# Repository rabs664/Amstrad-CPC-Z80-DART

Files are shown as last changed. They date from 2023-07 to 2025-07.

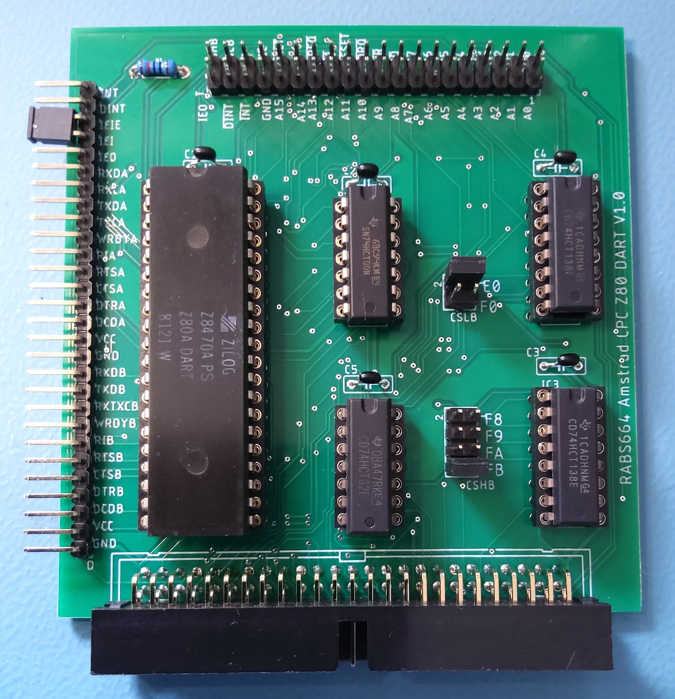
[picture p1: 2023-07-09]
Images/assembled-board.jpg

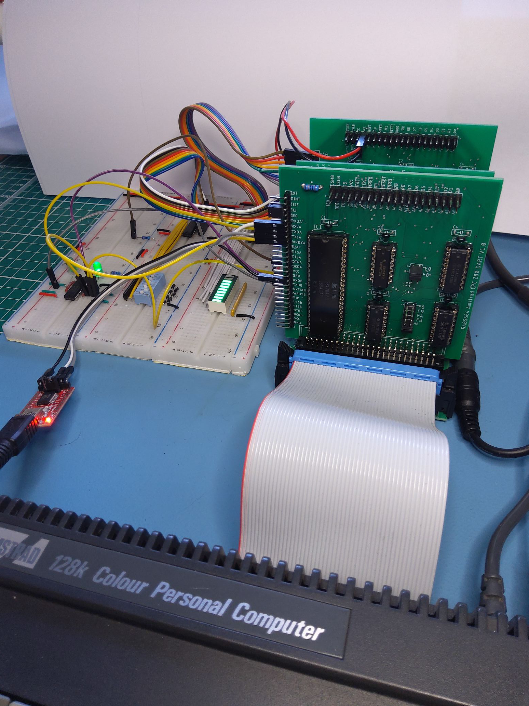
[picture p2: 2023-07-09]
Images/board-on-test.jpg

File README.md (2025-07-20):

# Amstrad CPC Z80 DART
Simple Z80 DART board compatible with the Amstrad CPC and MX4 connector.

assembled-board

## Objective
Prototyping board to learn about the Z80 DART, and how to write Z80 assembly using an Amstrad CPC.

## Background
Part of a number of modular cards using Z80 associated peripherals and the Amstrad CPC.

See also;
[Amstrad CPC 2855 PIO](https://github.com/rabs664/Amstrad-CPC-8255-PIO)

## Backplane
[CPC Amstrad Expansion Backplane by revaldinho](https://github.com/revaldinho/cpc_ram_expansion/wiki/CPC-Expansion-Backplane)

## IO Addressing
The IO Address can be selected using two sets of jumpers (CS_HB and CS_LB), supporting the following base address.

* F8E0 and F8F0
* F9E0 and F9F0
* FAE0 and FAF0
* FBE0 and FBF0

See [CPC Wiki IO Port Summary](https://www.cpcwiki.eu/index.php/I/O_Port_Summary) for a list of known IO ports used on the Amstrad CPC.

## Testing
The Z80 DART board has been built and simple testing has been completed on an Amstrad CPC 6128.

Note testing was completed with a Z80 CTC board for the baud clock generation. The Amstrad Clock can be used as a baud clock but this will result in a non standard baud rate.

Note also an FTDI Serial Adapter was used to connect to a putty session.

IEI was tied high (via a 10K resistor) using a jumper to IEIE. 

## PCBs
PCBs are available from [Seeed Studio](https://www.seeedstudio.com/Simple-Z80-DART-board-compatible-with-the-Amstrad-CPC-and-MX4-connecto-g-1395237).

## Components
This [Digi-Key List](https://www.digikey.co.uk/en/mylists/list/F0CQ96V54G) contains all components excluding the Z80 DART and FTDI Serial Adapter.

Note the right angled header for the port connections was not available at the time of producing this list but all other components were in stock for shipping immediately.

## Assembler
[RASM](https://github.com/EdouardBERGE/rasm)

## Resources
[CPCWiki](https://www.cpcwiki.eu/index.php/Main_Page)

Z80 Application by James W Coffron ISBN 0-89588-094-6

## Acknowledgements
[@revaldinho](https://github.com/revaldinho)

Don Prefontaine 

Peter Murray

[@EdouardBERGE](https://github.com/EdouardBERGE)

# Release History
## Version 1.0
* First Release

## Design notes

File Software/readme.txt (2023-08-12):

This folder contains software associated with the Amstrad CPC Z80 DART.

drttst01.asm is a test program written in Z80 Assembly (using RASM) which transmits "Hello World".

drttst02.asm is a test program written in Z80 Assembly (using RASM) which loops back characters received.

drtlib01.asm provides libary routines and macros for the DART.

ctclib01.asm provides libary routines and macros for the CTC.

cfwlib03.asm provides libary routines and macros from to access the CPC Firmware.

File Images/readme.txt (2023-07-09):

This folder contains some images of the Amstrad CPC Z80 DART board.

Note in the board-on-test image, the CTC and PIO boards can also be seen.

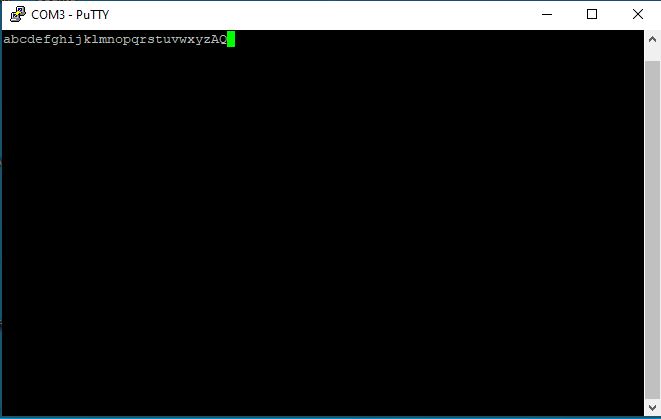
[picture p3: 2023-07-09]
Images/DRTTST02-Putty-Session.JPG

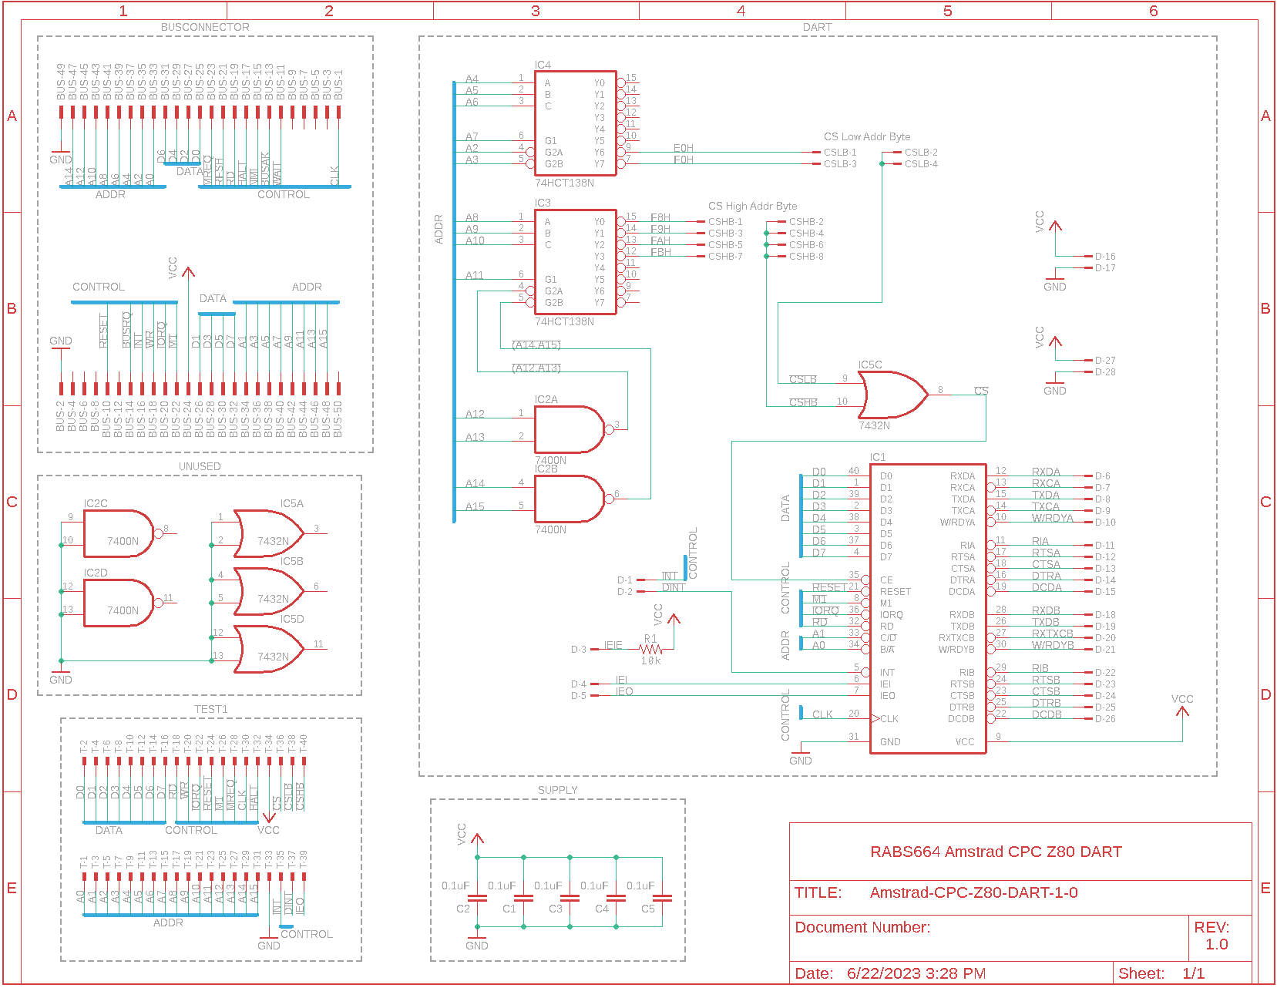
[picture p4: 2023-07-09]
Images/Amstrad-CPC-Z80-DART-1-0-SCH.png

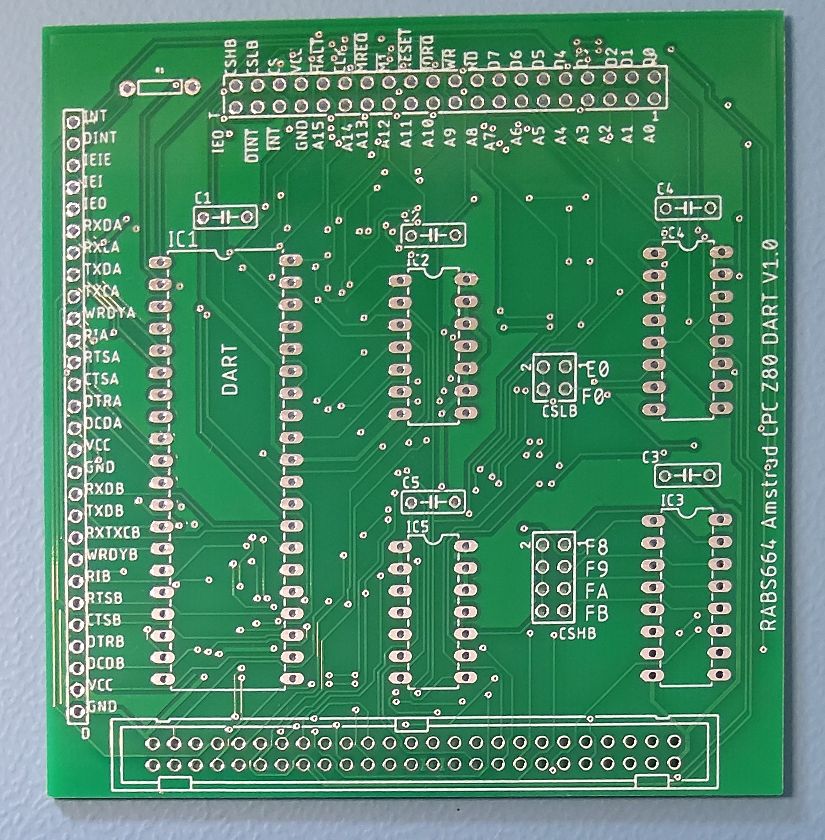
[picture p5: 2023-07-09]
Images/bare-board.jpg

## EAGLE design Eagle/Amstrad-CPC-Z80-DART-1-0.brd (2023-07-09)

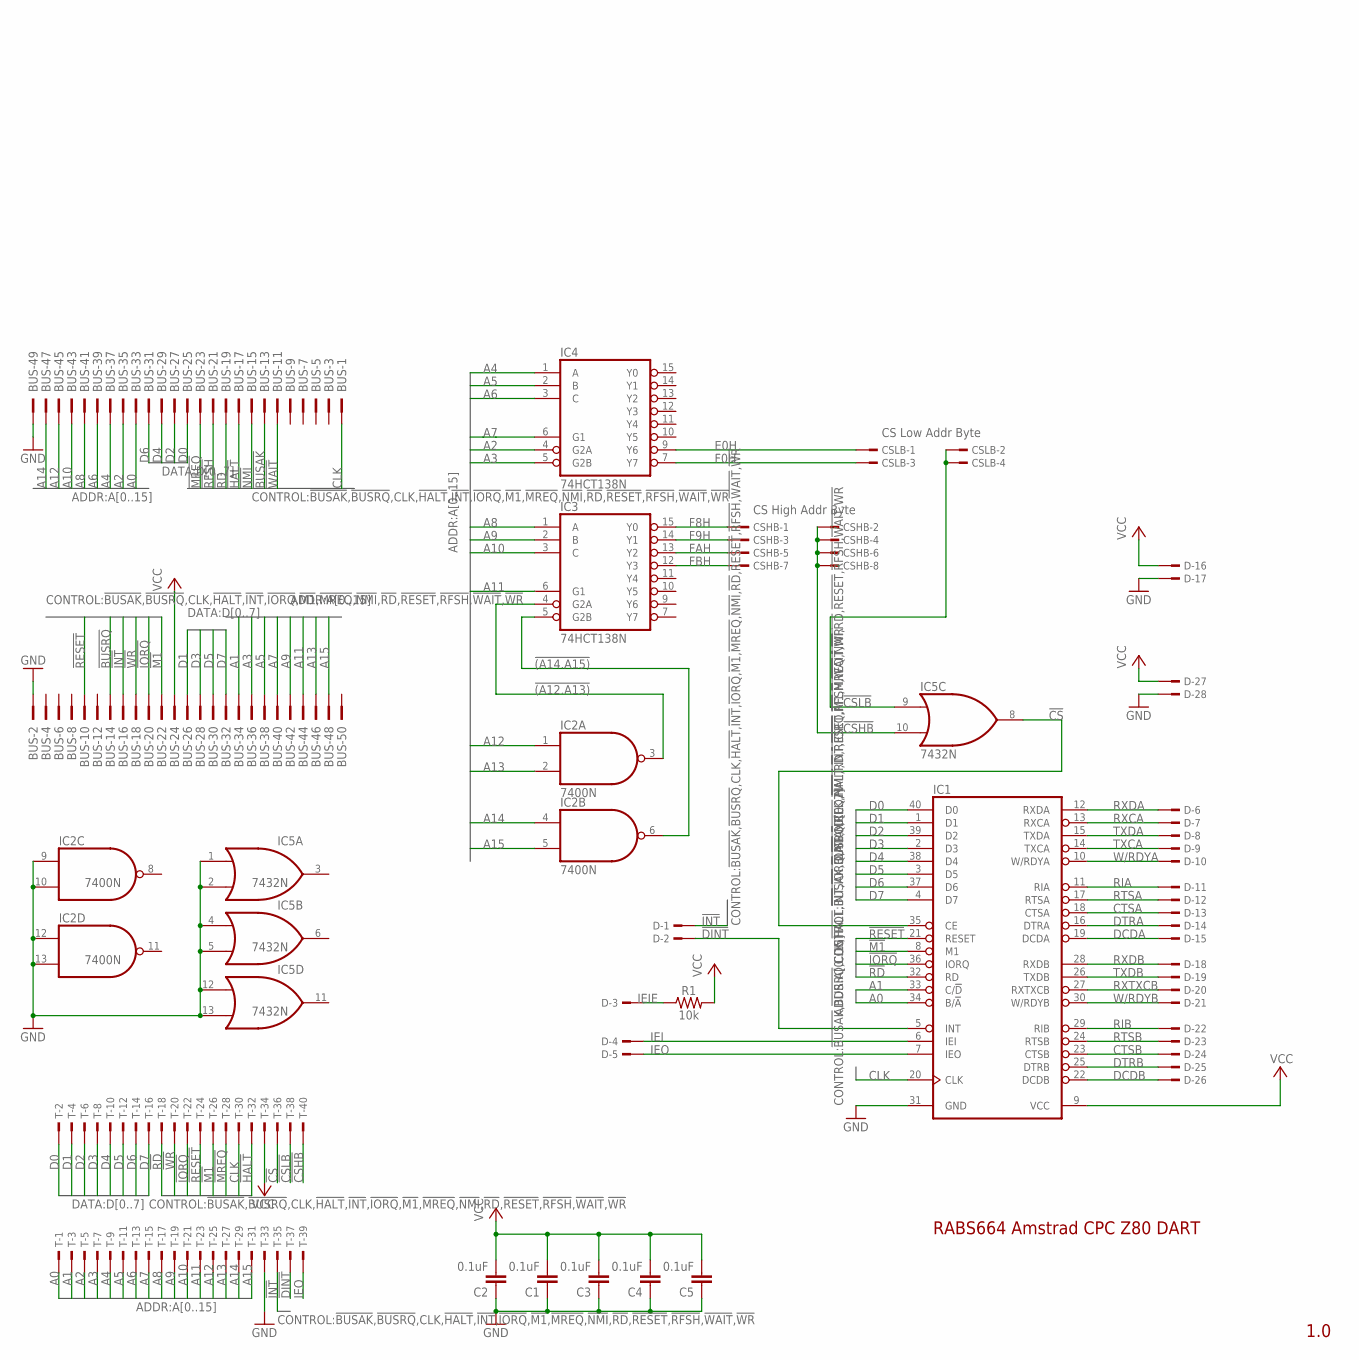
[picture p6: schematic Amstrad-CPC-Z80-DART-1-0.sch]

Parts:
BUS: 2550-; PAK100/2500-50
C1, C2, C3, C4, C5: 0.1uF; C050-025X075
CSHB: TSW-104-07-G-D; TSW-104-XX-G-D
CSLB: TSW-102-07-G-D; TSW-102-XX-G-D
D: TSW-128-07-G-S; TSW-128-XX-G-S
IC1: Z80DART; DIL40
IC2: 7400N; DIL14
IC3, IC4: 74HCT138N; DIL16
IC5: 7432N; DIL14
R1: 10k; AXIAL-0.3
T: TSW-120-07-G-D; TSW-120-XX-G-D

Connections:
!(A12.A13): IC2.3 (O), IC3.4 (G2A)
!(A14.A15): IC2.6 (O), IC3.5 (G2B)
!BUSAK: BUS.13
!BUSRQ: BUS.14
!CS: IC1.35 (CE), IC5.8 (O), T.36
!CSHB: CSHB.2, CSHB.4, CSHB.6, CSHB.8, IC5.10 (I1), T.40
!CSLB: CSLB.2, CSLB.4, IC5.9 (I0), T.38
!DINT: D.2, IC1.5 (INT), T.37
!HALT: BUS.17, T.32
!INT: BUS.16, D.1, T.35
!IORQ: BUS.20, IC1.36 (IORQ), T.22
!M1: BUS.22, IC1.8 (M1), T.26
!MREQ: BUS.23, T.28
!NMI: BUS.15
!RD: BUS.19, IC1.32 (RD), T.18
!RESET: BUS.10, IC1.21 (RESET), T.24
!RFSH: BUS.21
!WAIT: BUS.11
!WR: BUS.18, T.20
A0: BUS.33, IC1.34 (B/!A), T.1
A1: BUS.34, IC1.33 (C/!D), T.3
A2: BUS.35, IC4.4 (G2A), T.5
A3: BUS.36, IC4.5 (G2B), T.7
A4: BUS.37, IC4.1 (A), T.9
A5: BUS.38, IC4.2 (B), T.11
A6: BUS.39, IC4.3 (C), T.13
A7: BUS.40, IC4.6 (G1), T.15
A8: BUS.41, IC3.1 (A), T.17
A9: BUS.42, IC3.2 (B), T.19
A10: BUS.43, IC3.3 (C), T.21
A11: BUS.44, IC3.6 (G1), T.23
A12: BUS.45, IC2.1 (I0), T.25
A13: BUS.46, IC2.2 (I1), T.27
A14: BUS.47, IC2.4 (I0), T.29
A15: BUS.48, IC2.5 (I1), T.31
CLK: BUS.1, IC1.20 (CLK), T.30
CTSA: D.13, IC1.18 (CTSA)
CTSB: D.24, IC1.23 (CTSB)
D0: BUS.25, IC1.40 (D0), T.2
D1: BUS.26, IC1.1 (D1), T.4
D2: BUS.27, IC1.39 (D2), T.6
D3: BUS.28, IC1.2 (D3), T.8
D4: BUS.29, IC1.38 (D4), T.10
D5: BUS.30, IC1.3 (D5), T.12
D6: BUS.31, IC1.37 (D6), T.14
D7: BUS.32, IC1.4 (D7), T.16
DCDA: D.15, IC1.19 (DCDA)
DCDB: D.26, IC1.22 (DCDB)
DTRA: D.14, IC1.16 (DTRA)
DTRB: D.25, IC1.25 (DTRB)
E0H: CSLB.1, IC4.9 (Y6)
F0H: CSLB.3, IC4.7 (Y7)
F8H: CSHB.1, IC3.15 (Y0)
F9H: CSHB.3, IC3.14 (Y1)
FAH: CSHB.5, IC3.13 (Y2)
FBH: CSHB.7, IC3.12 (Y3)
GND: BUS.2, BUS.49, C1.1, C2.1, C3.1, C4.1, C5.1, D.17, D.28, IC1.31 (GND), IC2.7 (GND), IC2.9 (I0), IC2.10 (I1), IC2.12 (I0), IC2.13 (I1), IC3.8 (GND), IC4.8 (GND), IC5.1 (I0), IC5.2 (I1), IC5.4 (I0), IC5.5 (I1), IC5.7 (GND), IC5.12 (I0), IC5.13 (I1), T.33
IEI: D.4, IC1.6 (IEI)
IEIE: D.3, R1.P$1 (1)
IEO: D.5, IC1.7 (IEO), T.39
RIA: D.11, IC1.11 (RIA)
RIB: D.22, IC1.29 (RIB)
RTSA: D.12, IC1.17 (RTSA)
RTSB: D.23, IC1.24 (RTSB)
RXCA: D.7, IC1.13 (RXCA)
RXDA: D.6, IC1.12 (RXDA)
RXDB: D.18, IC1.28 (RXDB)
RXTXCB: D.20, IC1.27 (RXTXCB)
TXCA: D.9, IC1.14 (TXCA)
TXDA: D.8, IC1.15 (TXDA)
TXDB: D.19, IC1.26 (TXDB)
VCC: BUS.24, C1.2, C2.2, C3.2, C4.2, C5.2, D.16, D.27, IC1.9 (VCC), IC2.14 (VCC), IC3.16 (VCC), IC4.16 (VCC), IC5.14 (VCC), R1.P$2 (2), T.34
W/RDYA: D.10, IC1.10 (W/RDYA)
W/RDYB: D.21, IC1.30 (W/RDYB)

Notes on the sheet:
1.0
RABS664 Amstrad CPC Z80 DART
CS Low Addr Byte
CS High Addr Byte

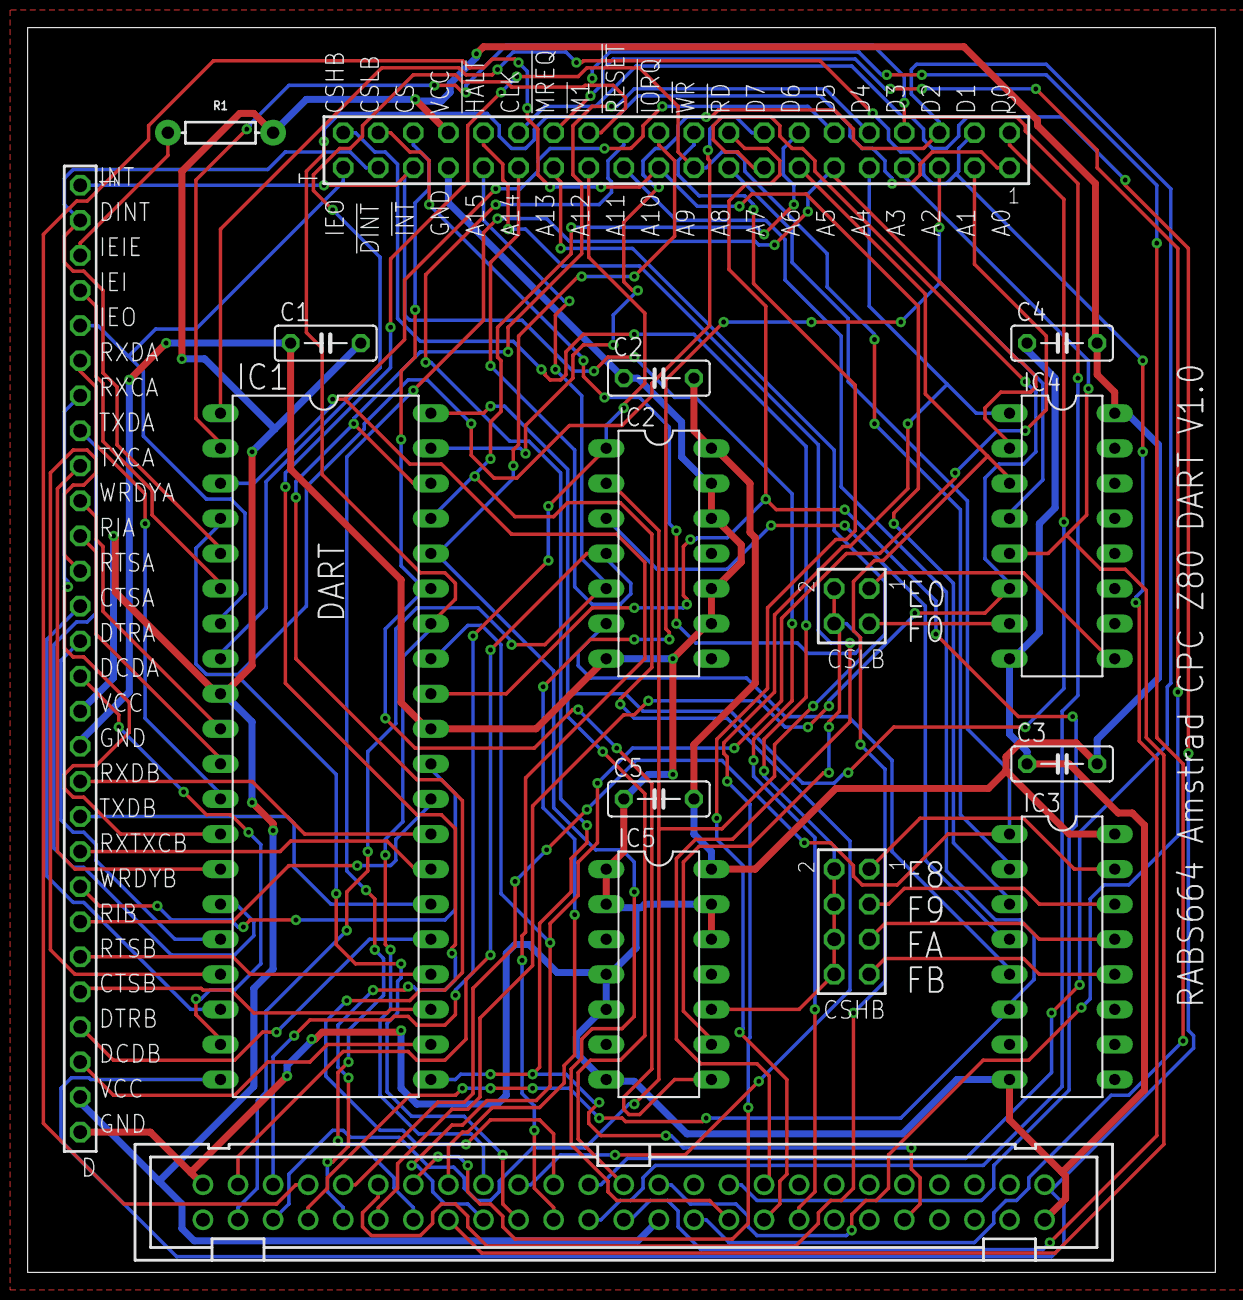
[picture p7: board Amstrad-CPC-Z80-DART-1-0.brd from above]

Board: 2 copper layers, 86.0 x 90.2 mm, 16 parts (0 on the bottom side), 69 nets.

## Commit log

2023-08-12 Update drttst02.asm
    Added FwTxtWrChar to print received characters on Amstrad CPC.
2023-08-25 Update README.md
    Added Seeed Studio reference for PCB.

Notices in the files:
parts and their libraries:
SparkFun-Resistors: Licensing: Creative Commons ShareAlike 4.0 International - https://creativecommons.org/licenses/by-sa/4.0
